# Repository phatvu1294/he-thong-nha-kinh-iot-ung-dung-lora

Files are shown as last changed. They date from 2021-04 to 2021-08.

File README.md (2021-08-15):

# Hệ thống nhà kính IO ứng dụng LoRa
*Hệ thống nhà kính IOT ứng dựng LoRa được phát triển dựa trên ESP32, Arduino, LoRa, MQTT, Nodejs và C# Winform*

### Giới thiệu
Đây là một dự án hoàn toàn mới tại Việt Nam, việc áp dụng IOT và công nghệ LoRa đã mở ra một bước đi mới trong nghành nông nghiệp. Đi đôi với cuộc cách mạng công nghệ 4.0, IOT là một phần thiết yếu để phát triển nông nghiệp. Với việc gần như được áp dụng vào thực tế, càng chứng tỏ đây chính là một dự án cấp thiết, việc nghiên cứu và phát triển thêm sẽ càng giúp cho đất nước chúng ta hội nhập và phát triển hơn nữa.

### Mô hình

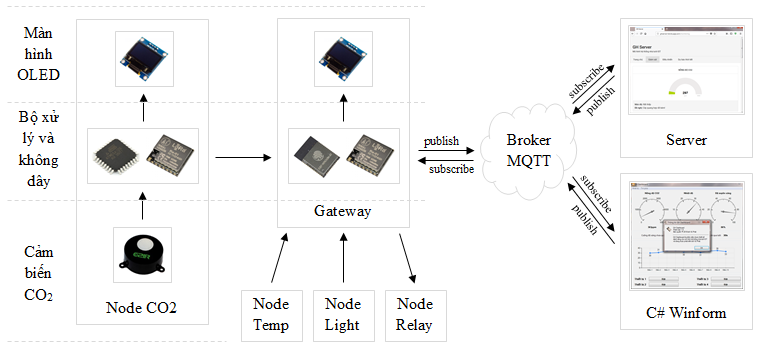
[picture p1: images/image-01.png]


Mô hình lấy Gateway làm trung tâm để xây dựng, Gateway được xây dựng bằng module ESP32, module LoRa Ra-01 và OLED, có nhiệm vụ là chờ tiếp nhận dữ liệu LoRa từ các Node cảm biến (Node CO2, Node Temp, Node Light), xử lý hiển thị OLED và publish chúng lên broker, sau đó được đẩy lên Server hoặc phần mềm điều khiển (C# Winform).

Node cảm biển, cụ thể ở đây là Node CO2 được xây dựng bằng vi điều khiển ATMega328, module LoRa Ra-01, OLED và cảm biến COZIR-AX-5000. Nhiệm vụ là đọc giá trị CO2 và truyền dữ liệu LoRa tới Gateway.

Gateway kết nối với Server hoặc phần mềm thông qua phương thức MQTT, đây là phương thức truyền nhanh, với tốc độ băng thông thấp, … Chúng có dạng publish/subscribe. Khi nhận được dữ liệu LoRa từ Node cảm biến. Gateway xử lý dữ liệu và publish lên broker một message thông qua một topic, lúc này Server hoặc phần mềm sẽ subscribe topic đó và lắng nghe liên tục message từ topic đó, chỉ cần có một dữ liệu gửi lên từ Gateway, lập tức Server và phần mềm sẽ cập nhật giá trị mới theo message đã nhận được, ngược lại, khi Server hoặc Gateway publish dữ liệu, Gateway sẽ subscribe và lắng nghe chúng, nếu có message gửi về từ Server hoặc phần mềm, lập tức Gateway nhận được và chuyển thành dữ liệu LoRa và truyền đi tức thời tới Node điều khiển (Node Relay).

Server được xây dựng trên nền tảng Node.js và phần mềm được xây dựng trên nền tảng C# .NET. Tất cả chúng đều đã có thư viện MQTT hỗ trợ, việc còn lại là do người lập trình sáng tạo chúng như thế nào mà thôi.

### Gateway

Gateway được xây dựng với hạt nhân là module ESP32 và module LoRa Ra-01. Module ESP32 sử dụng chip 32 bit lõi kép cho phép xử lý dữ liệu tốc độ cao, ổn định. Module LoRa Ra-01 sử dụng chip SX1278 hỗ trợ truyền không dây RF lên tận hàng Km.

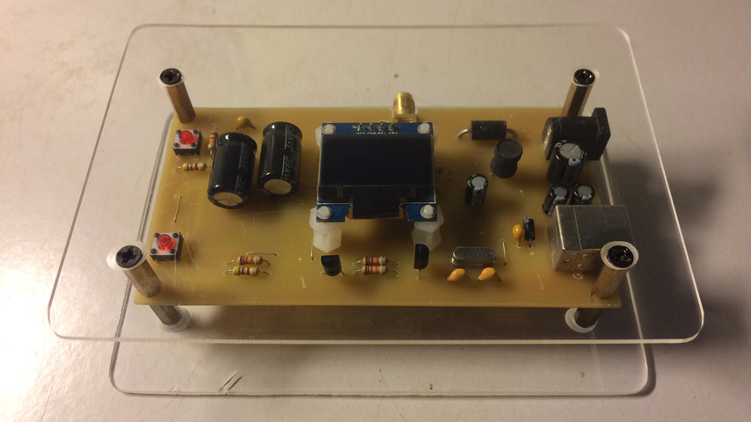
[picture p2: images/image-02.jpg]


### Node CO2

Node CO2 được xây dựng với vđk ATMega328 (Arduino), module LoRa Ra-01 và cảm biến COZIR-AX-5000. Cảm biến COZIR là cảm biến số cho phép đọc giá trị CO2 trực tiếp thông qua UART mà không cần phải tính toán gì nhiều.

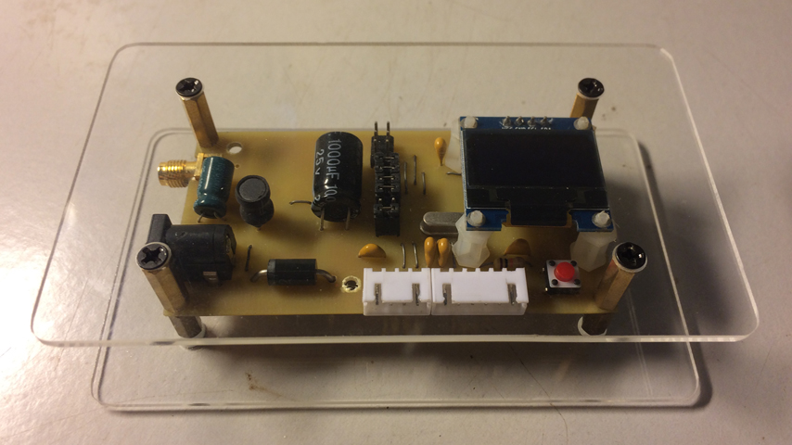
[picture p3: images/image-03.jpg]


### Server Nodejs

Server được xây dựng dựa trên nền tảng Node.js. Với việc sử dụng Socket.io cho phép Server hoạt động thời gian thực. Hệ thống đưa ra khuyến nghị ứng với từng giá trị. Ngoài ra còn có trang dự báo thời tiết cho phép xem tình hình thời tiết trong những ngày sắp tới.

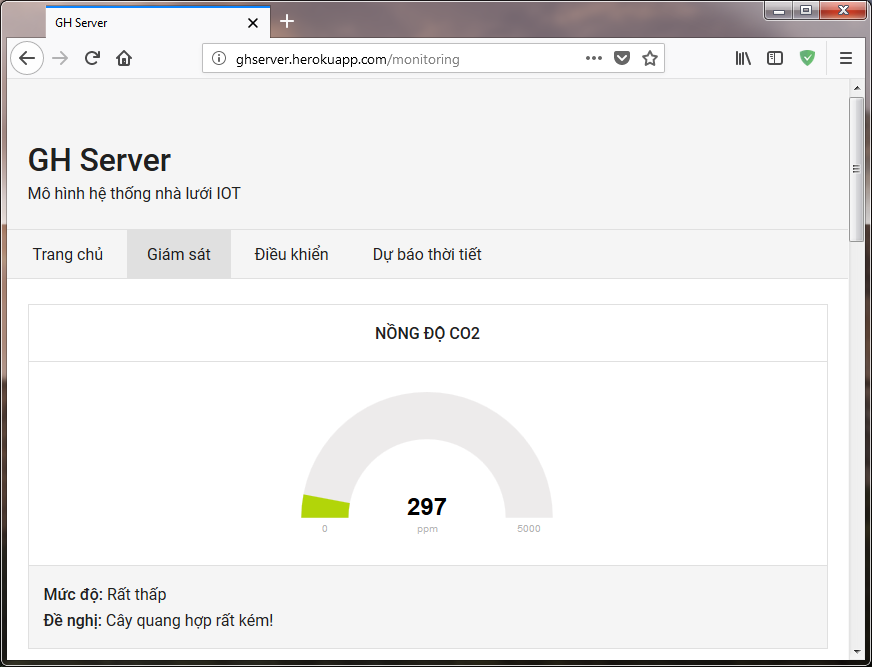
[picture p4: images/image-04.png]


### Phần mềm Winform

Phần mềm được xây dựng dựa trên nền tảng C# .NET. Hỗ trợ nhật ký cho phép người sử dụng theo dõi được sự thay đổi tức thời của các giá trị.

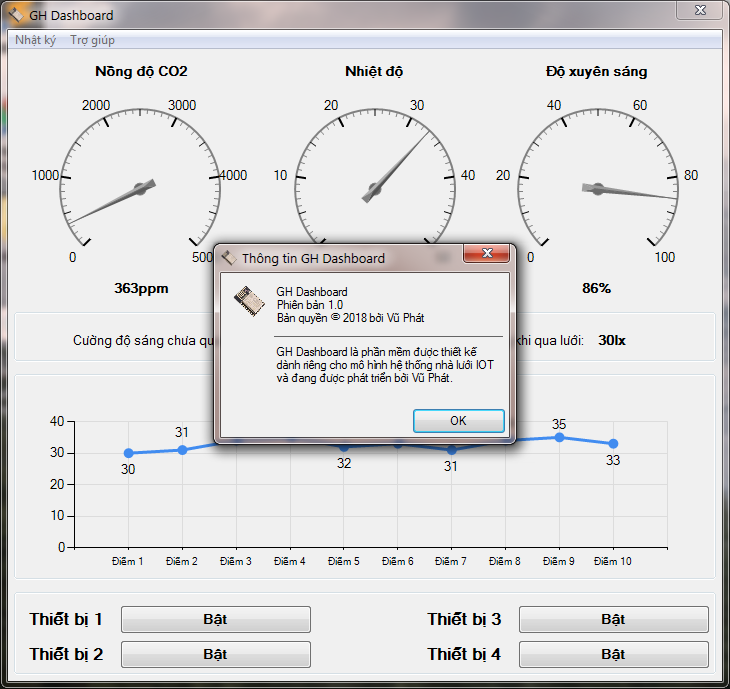
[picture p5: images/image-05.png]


### Video demo hệ thống

[https://www.youtube.com/watch?v=TktAAO-llQs](https://www.youtube.com/watch?v=TktAAO-llQs)

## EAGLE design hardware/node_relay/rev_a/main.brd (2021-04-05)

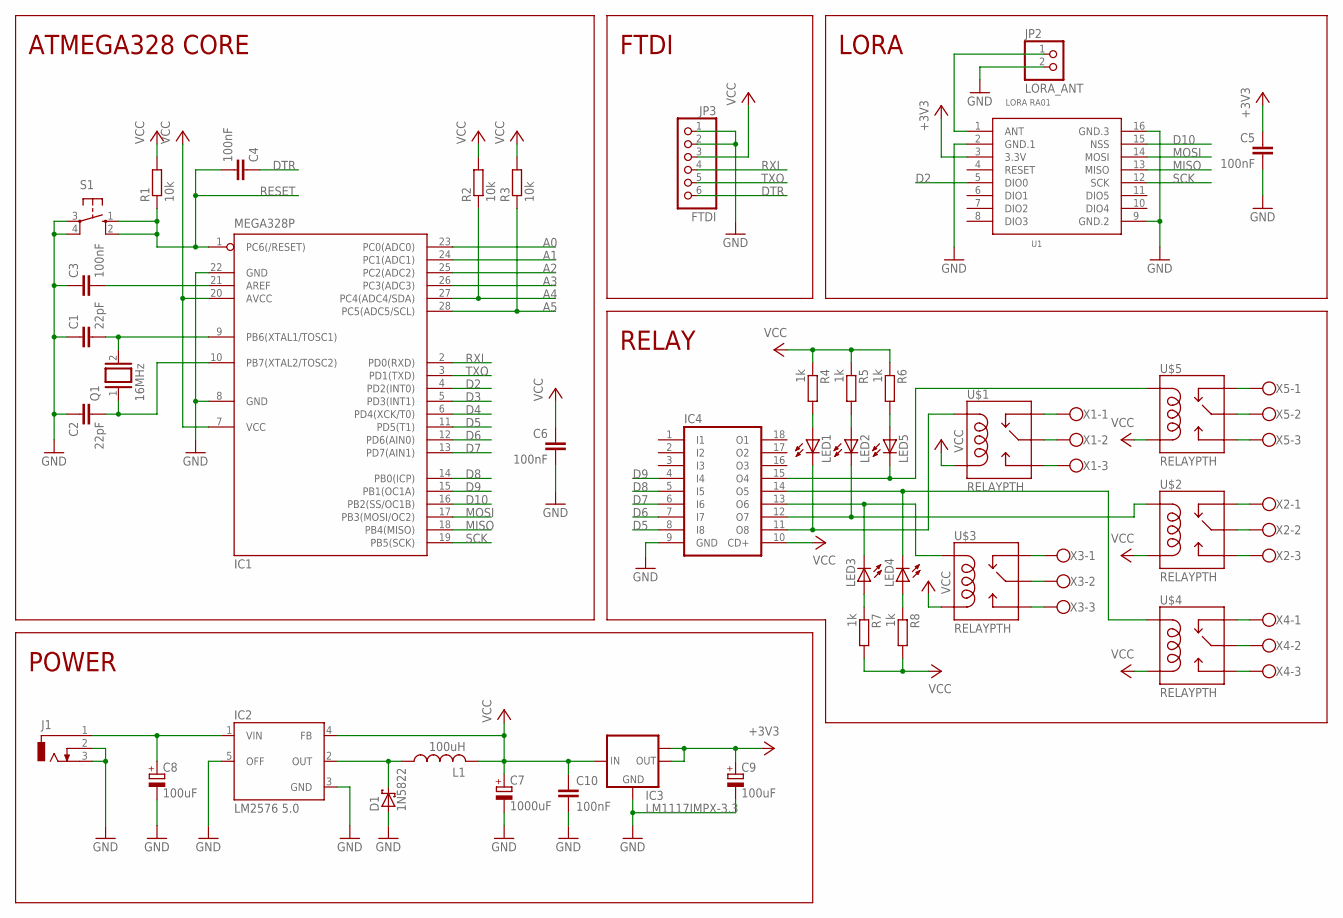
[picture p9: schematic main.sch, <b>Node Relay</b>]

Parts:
C1, C2: 22pF; C050-024X044
C3, C4, C5, C6, C10: 100nF; C050-024X044
C7: 1000uF; E5-13
C8: 100uF; E5-8,5
C9: 100uF; E3,5-10
D1: 1N5822; DO201T15
IC1: MEGA328P; DIL28-3
IC2: LM2576 5.0; TO263-5
IC3: LM1117IMPX-3.3; SOT223
IC4: ULN2803A; DIL18
J1: DCJ0303
JP2: LORA_ANT; 1X02
JP3: FTDI; 1X06
L1: 100uH; 6000-XXXX-RC
LED1, LED2, LED3, LED4, LED5: LED3MM
Q1: 16MHz; QS
R1, R2, R3: 10k; 0207/10
R4, R5, R6, R7, R8: 1k; 0207/10
S1: 10-XX; B3F-10XX
U1: LORA RA01; LORA-RA1-SMD
U$1, U$2, U$3, U$4, U$5: RELAYPTH; SRD-05VDC-SL-C
X1, X2, X3, X4, X5: W237-103

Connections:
+3V3: C5.1, C9.+, IC3.2 (OUT), IC3.TAB (OUT1), U1.3 (3.3V)
A0: IC1.23 (PC0(ADC0))
A1: IC1.24 (PC1(ADC1))
A2: IC1.25 (PC2(ADC2))
A3: IC1.26 (PC3(ADC3))
A4: IC1.27 (PC4(ADC4/SDA)), R2.1
A5: IC1.28 (PC5(ADC5/SCL)), R3.1
D2: IC1.4 (PD2(INT0)), U1.5 (DIO0)
D3: IC1.5 (PD3(INT1))
D4: IC1.6 (PD4(XCK/T0))
D5: IC1.11 (PD5(T1)), IC4.8 (I8)
D6: IC1.12 (PD6(AIN0)), IC4.7 (I7)
D7: IC1.13 (PD7(AIN1)), IC4.6 (I6)
D8: IC1.14 (PB0(ICP)), IC4.5 (I5)
D9: IC1.15 (PB1(OC1A)), IC4.4 (I4)
D10: IC1.16 (PB2(SS/OC1B)), U1.15 (NSS)
DTR: C4.1, JP3.6
GND: C1.1, C2.1, C3.1, C5.2, C6.2, C7.-, C8.-, C9.-, C10.2, D1.A, IC1.8 (GND), IC1.22 (GND), IC2.3 (GND), IC2.5 (OFF), IC3.1 (GND), IC4.9 (GND), J1.2, J1.3, JP2.2, JP3.1, JP3.2, S1.3, S1.4 (P1), U1.2 (GND.1), U1.9 (GND.2), U1.16 (GND.3)
MISO: IC1.18 (PB4(MISO)), U1.13 (MISO)
MOSI: IC1.17 (PB3(MOSI/OC2)), U1.14 (MOSI)
unnamed: JP2.1, U1.1 (ANT)
unnamed: C1.2, IC1.9 (PB6(XTAL1/TOSC1)), Q1.2
unnamed: C2.2, IC1.10 (PB7(XTAL2/TOSC2)), Q1.1
unnamed: C3.2, IC1.21 (AREF)
unnamed: C8.+, IC2.1 (VIN), J1.1
unnamed: D1.C, IC2.2 (OUT), L1.1
unnamed: U$1.SWCLOSED (SWCLOSE), X1.1
unnamed: U$1.SWCOMMON, X1.2
unnamed: U$1.SWOPEN, X1.3
unnamed: U$3.SWCOMMON, X3.2
unnamed: U$3.SWCLOSED (SWCLOSE), X3.1
unnamed: U$3.SWOPEN, X3.3
unnamed: U$4.SWCLOSED (SWCLOSE), X4.1
unnamed: U$4.SWCOMMON, X4.2
unnamed: U$4.SWOPEN, X4.3
unnamed: U$2.SWOPEN, X2.3
unnamed: U$2.SWCLOSED (SWCLOSE), X2.1
unnamed: U$2.SWCOMMON, X2.2
unnamed: IC4.11 (O8), LED1.K (C), U$1.COIL1
unnamed: IC4.12 (O7), LED2.K (C), U$2.COIL1
unnamed: IC4.13 (O6), LED3.K (C), U$3.COIL1
unnamed: IC4.14 (O5), LED4.K (C), U$4.COIL1
unnamed: U$5.SWCLOSED (SWCLOSE), X5.1
unnamed: U$5.SWOPEN, X5.3
unnamed: U$5.SWCOMMON, X5.2
unnamed: IC4.15 (O4), LED5.K (C), U$5.COIL1
unnamed: LED1.A, R4.2
unnamed: LED2.A, R5.2
unnamed: LED5.A, R6.2
unnamed: LED3.A, R7.1
unnamed: LED4.A, R8.1
RESET: C4.2, IC1.1 (PC6(/RESET)), R1.1, S1.1 (S), S1.2 (S1)
RXI: IC1.2 (PD0(RXD)), JP3.4
SCK: IC1.19 (PB5(SCK)), U1.12 (SCK)
TXO: IC1.3 (PD1(TXD)), JP3.5
VCC: C6.1, C7.+, C10.1, IC1.7 (VCC), IC1.20 (AVCC), IC2.4 (FB), IC3.3 (IN), IC4.10 (CD+), JP3.3, L1.2, R1.2, R2.2, R3.2, R4.1, R5.1, R6.1, R7.2, R8.2, U$1.COIL0, U$2.COIL0, U$3.COIL0, U$4.COIL0, U$5.COIL0

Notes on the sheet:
LORA
ATMEGA328 CORE
FTDI
POWER
RELAY

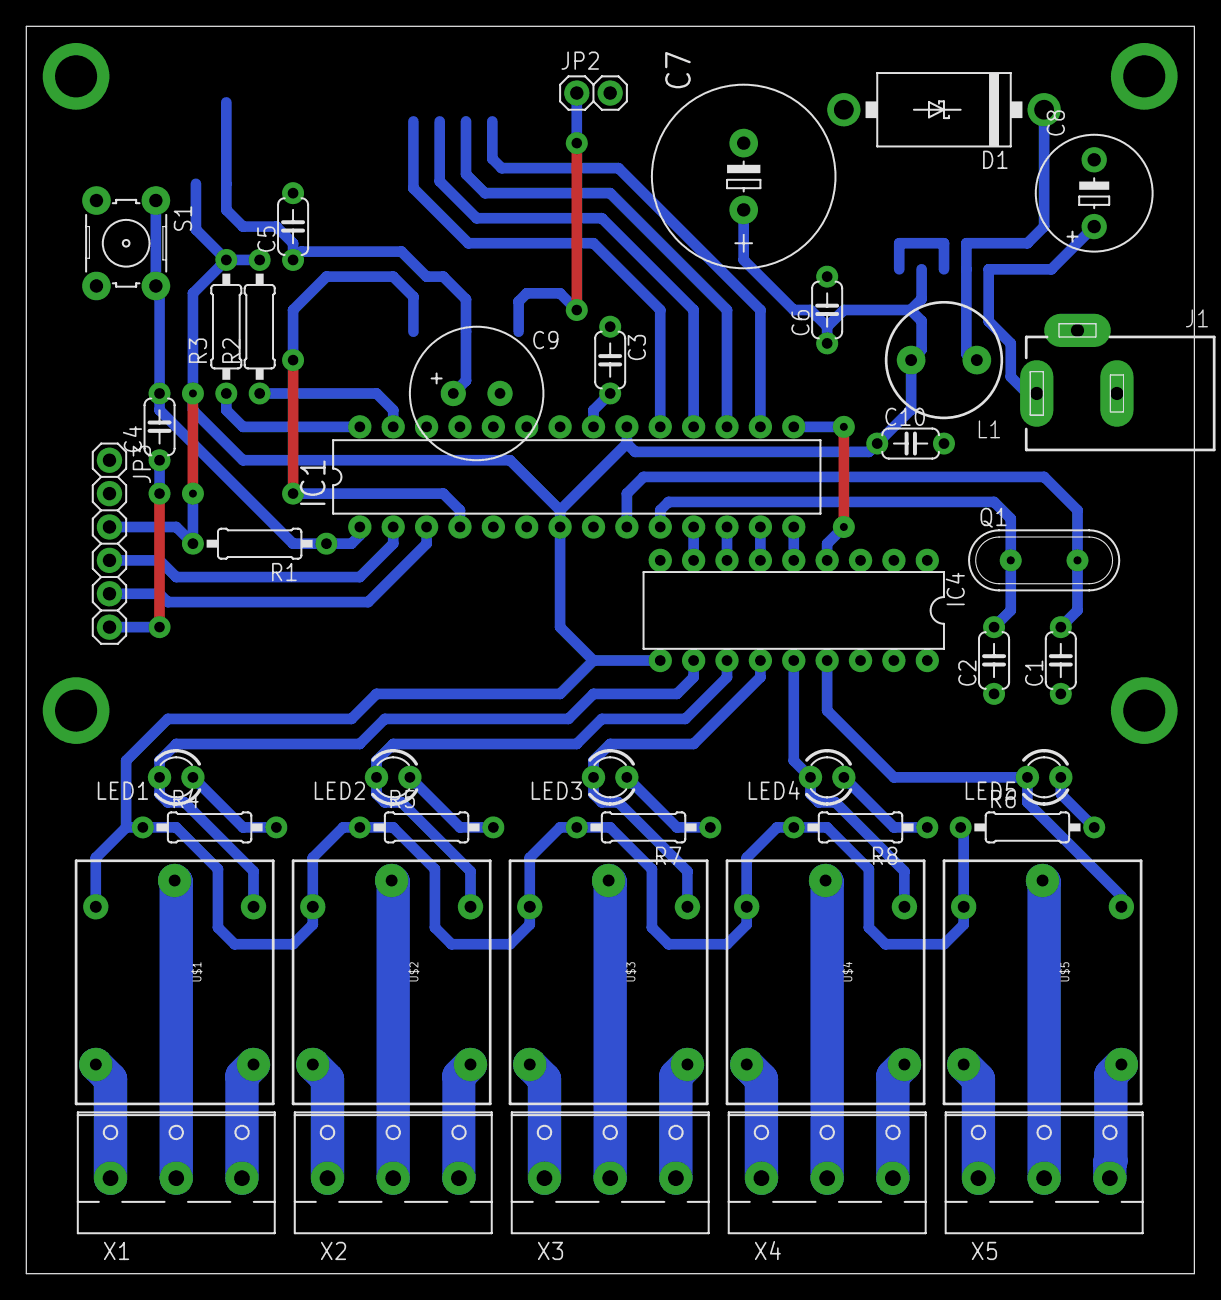
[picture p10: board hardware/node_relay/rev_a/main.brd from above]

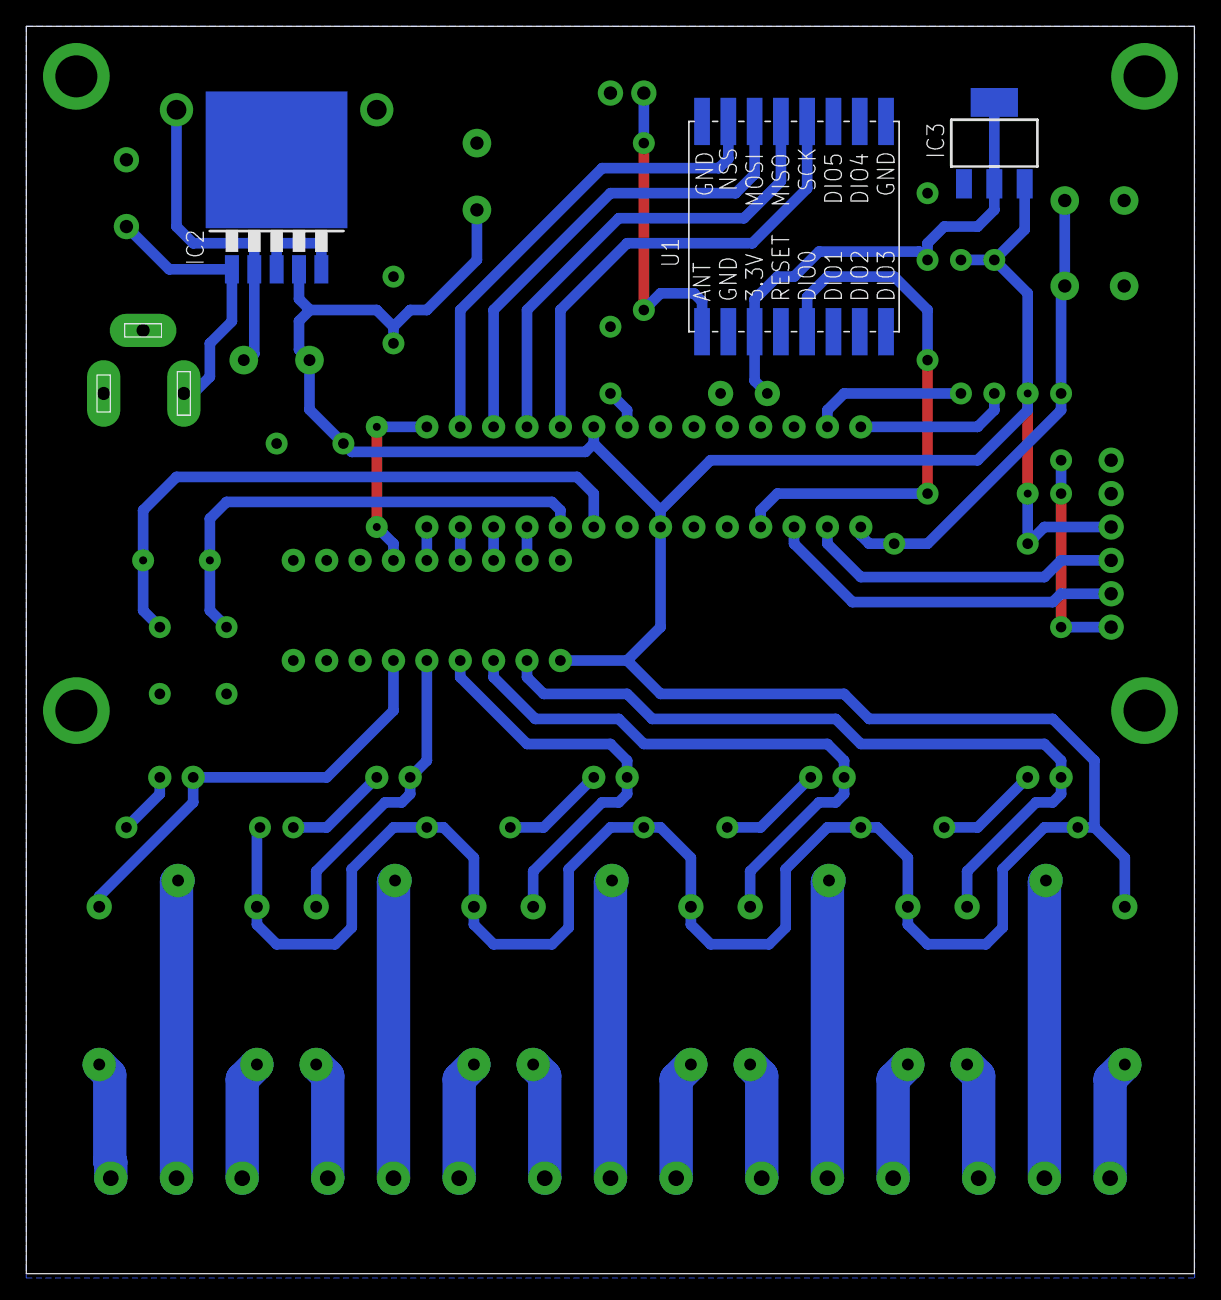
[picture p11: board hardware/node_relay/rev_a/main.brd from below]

Board: 2 copper layers, 88.9 x 94.9 mm, 45 parts (3 on the bottom side), 50 nets.

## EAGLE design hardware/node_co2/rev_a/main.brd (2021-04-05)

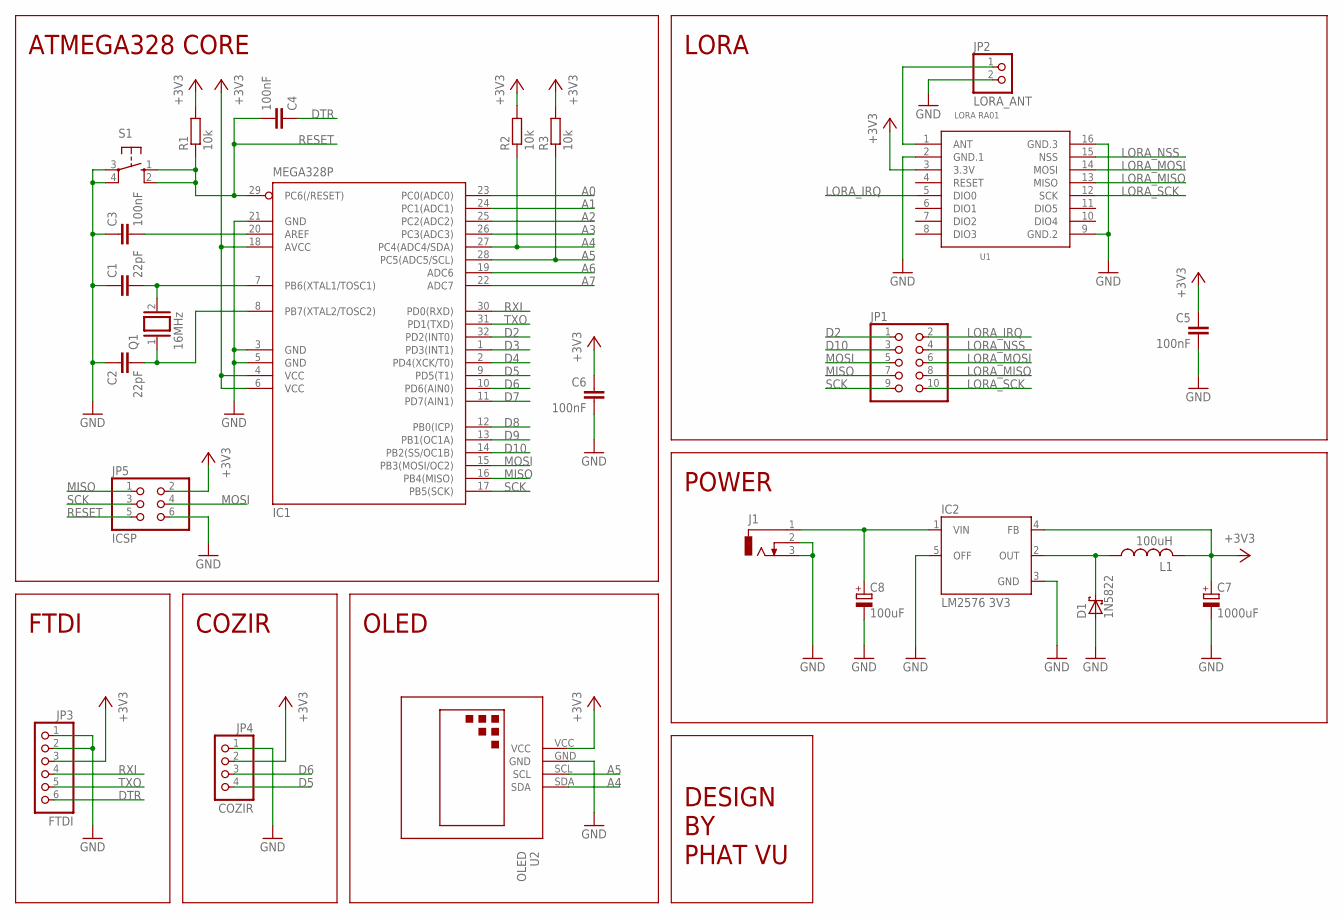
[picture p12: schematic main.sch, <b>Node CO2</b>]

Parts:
C1, C2: 22pF; C050-024X044
C3, C4, C5, C6: 100nF; C050-024X044
C7: 1000uF; E5-13
C8: 100uF; E5-8,5
D1: 1N5822; DO201T15
IC1: MEGA328P; TQFP32-08
IC2: LM2576 3V3; TO263-5
J1: DCJ0303
JP1: PINHD-2X5; 2X05
JP2: LORA_ANT; 1X02
JP3: FTDI; 1X06
JP4: COZIR; 1X04
JP5: ICSP; 2X03
L1: 100uH; 6000-XXXX-RC
Q1: 16MHz; QS
R1, R2, R3: 10k; 0207/10
S1: 10-XX; B3F-10XX
U1: LORA RA01; LORA-RA1-SMD
U2: OLED; OLED-096-I2C

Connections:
+3V3: C5.1, C6.1, C7.+, IC1.4 (VCC), IC1.6 (VCC), IC1.18 (AVCC), IC2.4 (FB), JP3.3, JP4.2, JP5.2, L1.2, R1.2, R2.2, R3.2, U1.3 (3.3V), U2.VCC
A0: IC1.23 (PC0(ADC0))
A1: IC1.24 (PC1(ADC1))
A2: IC1.25 (PC2(ADC2))
A3: IC1.26 (PC3(ADC3))
A4: IC1.27 (PC4(ADC4/SDA)), R2.1, U2.SDA
A5: IC1.28 (PC5(ADC5/SCL)), R3.1, U2.SCL
A6: IC1.19 (ADC6)
A7: IC1.22 (ADC7)
D2: IC1.32 (PD2(INT0)), JP1.1
D3: IC1.1 (PD3(INT1))
D4: IC1.2 (PD4(XCK/T0))
D5: IC1.9 (PD5(T1)), JP4.4
D6: IC1.10 (PD6(AIN0)), JP4.3
D7: IC1.11 (PD7(AIN1))
D8: IC1.12 (PB0(ICP))
D9: IC1.13 (PB1(OC1A))
D10: IC1.14 (PB2(SS/OC1B)), JP1.3
DTR: C4.1, JP3.6
GND: C1.1, C2.1, C3.1, C5.2, C6.2, C7.-, C8.-, D1.A, IC1.3 (GND), IC1.5 (GND), IC1.21 (GND), IC2.3 (GND), IC2.5 (OFF), J1.2, J1.3, JP2.2, JP3.1, JP3.2, JP4.1, JP5.6, S1.3, S1.4 (P1), U1.2 (GND.1), U1.9 (GND.2), U1.16 (GND.3), U2.GND
LORA_IRQ: JP1.2, U1.5 (DIO0)
LORA_MISO: JP1.8, U1.13 (MISO)
LORA_MOSI: JP1.6, U1.14 (MOSI)
LORA_NSS: JP1.4, U1.15 (NSS)
LORA_SCK: JP1.10, U1.12 (SCK)
MISO: IC1.16 (PB4(MISO)), JP1.7, JP5.1
MOSI: IC1.15 (PB3(MOSI/OC2)), JP1.5, JP5.4
unnamed: JP2.1, U1.1 (ANT)
unnamed: C1.2, IC1.7 (PB6(XTAL1/TOSC1)), Q1.2
unnamed: C2.2, IC1.8 (PB7(XTAL2/TOSC2)), Q1.1
unnamed: C3.2, IC1.20 (AREF)
unnamed: C8.+, IC2.1 (VIN), J1.1
unnamed: D1.C, IC2.2 (OUT), L1.1
RESET: C4.2, IC1.29 (PC6(/RESET)), JP5.5, R1.1, S1.1 (S), S1.2 (S1)
RXI: IC1.30 (PD0(RXD)), JP3.4
SCK: IC1.17 (PB5(SCK)), JP1.9, JP5.3
TXO: IC1.31 (PD1(TXD)), JP3.5

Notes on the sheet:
LORA
ATMEGA328 CORE
FTDI
COZIR
OLED
POWER
DESIGN BY PHAT VU

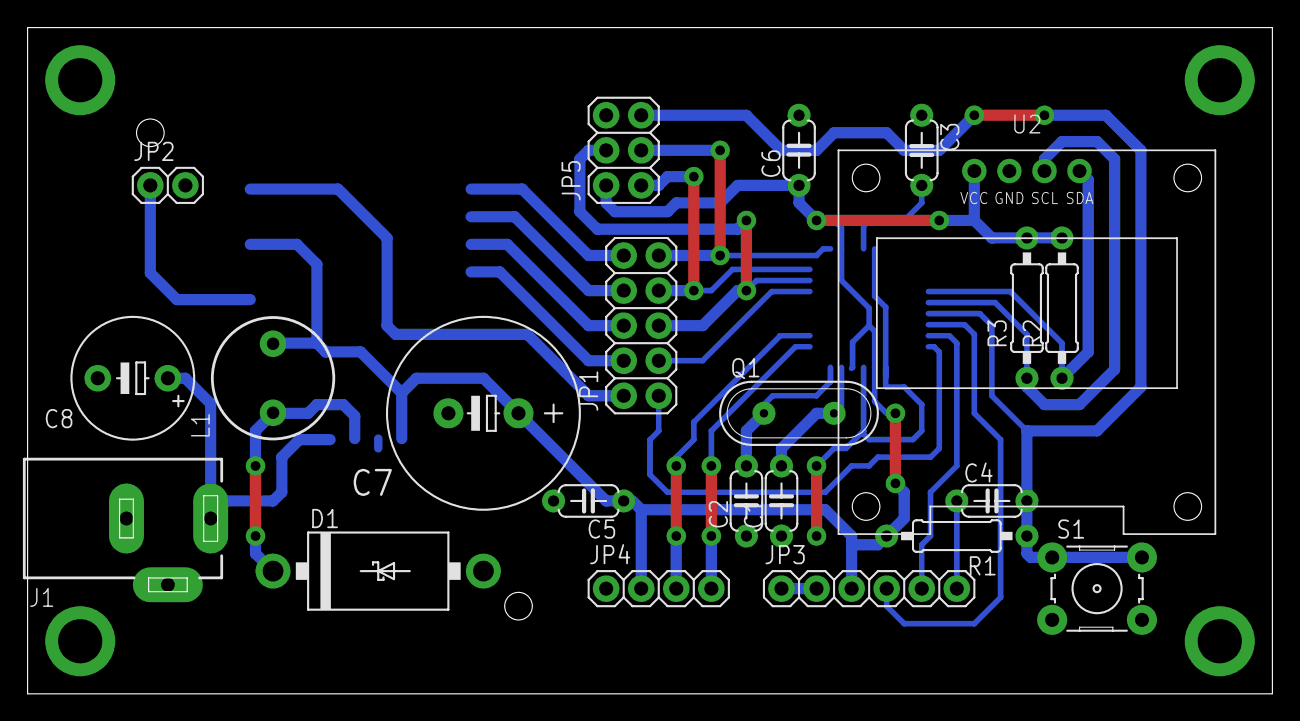
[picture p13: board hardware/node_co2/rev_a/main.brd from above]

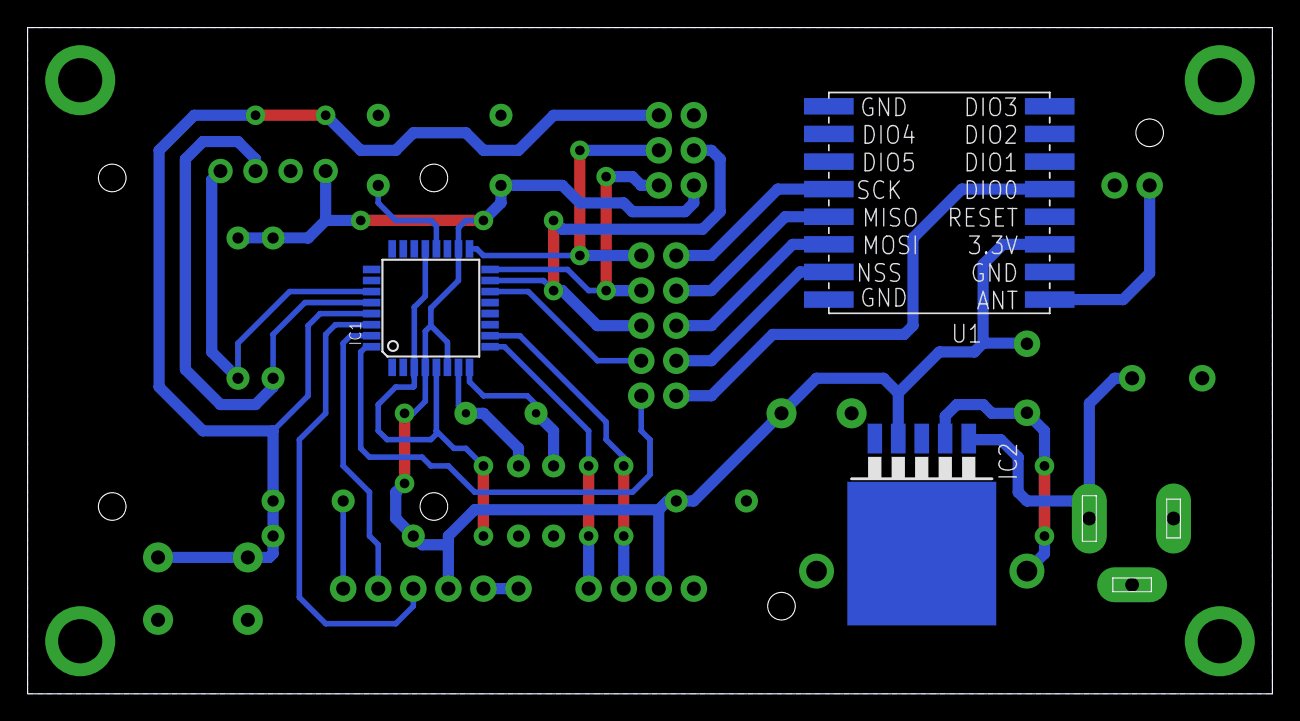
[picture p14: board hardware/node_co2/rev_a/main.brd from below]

Board: 2 copper layers, 90.2 x 48.3 mm, 25 parts (3 on the bottom side), 26 nets.

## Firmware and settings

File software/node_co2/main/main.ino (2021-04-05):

/*******************************************************************************
  Bao gồm
*******************************************************************************/

// Thư viện OLED
#include "ssd1306.h"
#include "images.h"

// Thư viện COZIR
#include <SoftwareSerial.h>
#include "cozir.h"

// Thư viện Lora
#include <SPI.h>
#include <RHDatagram.h>
#include <RH_RF95.h>

/*******************************************************************************
  Định nghĩa
*******************************************************************************/

// Địa chỉ Lora
#define GATEWAY_ADDRESS     0
#define NODECO2_ADDRESS     1

/*******************************************************************************
  Biến
*******************************************************************************/

// Lora
RH_RF95 driver;
RHDatagram manager(driver, NODECO2_ADDRESS);
bool loraSendOK = false, loraReceiveOK = false;
unsigned long loraSendMillis = 0, loraReceiveMillis = 0, loraInterval = 2000;

// COZIR
SoftwareSerial nss(5, 6);
COZIR czr(nss);

// Mảng giá trị CO2
char co2Arr[6];

// Định thời
unsigned long previousMillis = 0;
unsigned long interval = 1000;

/*******************************************************************************
  Hàm khởi tạo
*******************************************************************************/

void setup() {
  // Khỏi tạo OLED
  ssd1306_128x64_i2c_init();

  // Đầy màn hình
  ssd1306_fillScreen(0x00);

  // Đặt phông chữ
  ssd1306_setFixedFont(ssd1306xled_font6x8);

  // Hiển thị bản quyền tác giả và hình sản phẩm
  ssd1306_printFixed(14,  0, "(c) 2018 PHAT VU", STYLE_NORMAL);
  ssd1306_drawBitmap(0, 18, Product_bg_width, Product_bg_height, Product_bg_bits);

  // COZIR chế độ 2
  czr.SetOperatingMode(CZR_POLLING);

  // COZIR hiệu chỉnh không khí
  czr.CalibrateFreshAir();

  delay(3000);

  // Xóa màn hình
  ssd1306_clearScreen();

  // Hiển thị tên sản phẩm
  ssd1306_printFixed(66, 0, "NODE", STYLE_NORMAL);
  ssd1306_printFixed(66, 8, "v1.0", STYLE_NORMAL);
  ssd1306_printFixedN(92, 0, "CO2", STYLE_NORMAL, FONT_SIZE_2X);

  // Khởi tạo Lora
  manager.init();

  // Lora chế độ PA Boost 20dBm (Chậm + Khoảng cách xa)
  //driver.setModemConfig(RH_RF95::Bw31_25Cr48Sf512);
  //driver.setTxPower(20);
}

/*******************************************************************************
  Hàm lặp vô hạn
*******************************************************************************/

void loop() {
  // Hiển thị biểu tượng lora
  ssd1306_drawBitmap(0, 0, Lora_icon_width, Lora_icon_height, Lora_icon_bits);

  // Nếu Lora gửi thành công thì hiện biểu tượng gửi thành công và ngược lại
  if (loraSendOK) {
    ssd1306_drawBitmap(16, 0, Send_icon_width, Send_icon_height, Send_icon_bits);
  } else {
    ssd1306_drawBitmap(16, 0, Default_icon_width, Default_icon_height, Default_icon_bits);
  }

  // Nếu Lora nhận thành công thì hiện biểu tượng nhận thành công và ngược lại
  if (loraReceiveOK) {
    ssd1306_drawBitmap(16, 9, Receive_icon_width, Receive_icon_height, Receive_icon_bits);
  } else {
    ssd1306_drawBitmap(16, 9, Default_icon_width, Default_icon_height, Default_icon_bits);
  }

  // Nếu Lora sẵn sàng
  if (manager.available()) {
    // Biến bộ đệm
    uint8_t buf[RH_RF95_MAX_MESSAGE_LEN];

    // Biến độ rộng bộ đệm
    uint8_t len = sizeof(buf);

    // Biến địa chỉ Lora
    uint8_t from;

    // Nếu nhận được dữ liệu Lora
    if (manager.recvfrom(buf, &len, &from)) {

      // Nếu từ Gateway
      if (from == GATEWAY_ADDRESS) {
        // Lora nhận thành công
        loraReceiveOK = true;
        loraReceiveMillis = millis();

        delay(500);

        // Nếu gửi giá trị CO2 đến Gateway thành công
        if (manager.sendto((uint8_t *)co2Arr, (uint8_t)sizeof(co2Arr), GATEWAY_ADDRESS)) {
          // Lora gửi thành công
          loraSendOK = true;
          loraSendMillis = millis();
        }
      }
    }
  }

  // Biến thời điểm hiện tại
  unsigned long currentMillis1 = millis();

  // Chạy định thời với sau khoảng thời gian đặt trước
  if (currentMillis1 - previousMillis >= interval || previousMillis == 0) {
    previousMillis = currentMillis1;

    // Biến giá trị CO2
    int co2 = (int)czr.CO2();

    // Chuỗi giá trị CO2
    String co2Str = String(co2);

    // Chuyển chuỗi giá trị CO2 sang mảng giá trị CO2
    co2Str.toCharArray(co2Arr, sizeof(co2Arr));

    // Hiển thị hình CO2
    ssd1306_drawBitmap(0, 18, CO2_bg_width, CO2_bg_height, CO2_bg_bits);

    // Hiển thị tiêu đề CO2
    ssd1306_printFixed(50, 27, "Nong do (ppm)", STYLE_NORMAL);

    // Xóa giá trị CO2 hiện hành
    ssd1306_clearBlock(50, 45, 78, 16);

    // Hiển thị giá trị CO2
    ssd1306_printFixedN(64, 45, co2Str.c_str(), STYLE_NORMAL, FONT_SIZE_2X);
  }

  // Biến thời điểm hiện tại
  unsigned long currentMillis2 = millis();

  // Ẩn biểu tượng Lora gửi thành công sau thời gian định trước
  if ((currentMillis2 - loraSendMillis >= loraInterval) && loraSendOK) {
    loraSendOK = false;
  }

  // Ẩn biểu tượng Lora nhận thành công sau thời gian định trước
  if ((currentMillis2 - loraReceiveMillis >= loraInterval) && loraReceiveOK) {
    loraReceiveOK = false;
  }
}

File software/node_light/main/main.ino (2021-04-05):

/*******************************************************************************
  Bao gồm
*******************************************************************************/

// Thư viện LCD
#include <LiquidCrystal.h>

// Thư viện BH1750
#include <Wire.h>
#include <BH1750.h>

// Thư viện Lora
#include <RHDatagram.h>
#include <RH_RF95.h>
#include <SPI.h>

/*******************************************************************************
  Định nghĩa
*******************************************************************************/

// Địa chỉ Lora
#define GATEWAY_ADDRESS     0
#define NODELIGHT_ADDRESS   3

// Ký tự tự tạo
byte sendChar[] = {0x01, 0x03, 0x05, 0x01, 0x01, 0x01, 0x01, 0x00};
byte receiveChar[] = {0x10, 0x10, 0x10, 0x10, 0x14, 0x18, 0x10, 0x00};

/*******************************************************************************
  Biến
*******************************************************************************/

// LCD
LiquidCrystal lcd(9, 8, 7, 6, 5, 4);

// BH1750
BH1750 lightMeter1(0x23);
BH1750 lightMeter2(0x5c);

// Lora
RH_RF95 driver;
RHDatagram manager(driver, NODELIGHT_ADDRESS);
bool loraSendOK = false, loraReceiveOK = false;
unsigned long loraSendMillis = 0, loraReceiveMillis = 0, loraInterval = 2000;

// Mảng cường độ sáng
char lightArr[13];

// Định thời
unsigned long previousMillis = 0;
unsigned long interval = 1000;

/*******************************************************************************
  Hàm khởi tạo
*******************************************************************************/

void setup() {
  // Khởi tạo LCD
  lcd.begin(16, 2);
  lcd.createChar(0, sendChar);
  lcd.createChar(1, receiveChar);

  // Hiển thị bản quyền và tác giả
  lcd.setCursor(0, 0);
  lcd.print("NODE LIGHT  v1.0");
  lcd.setCursor(0, 1);
  lcd.print("(c) 2018 PHAT VU");

  // Khởi tạo BH1750
  Wire.begin();
  lightMeter1.begin();
  lightMeter2.begin();

  // Khởi tạo Lora
  manager.init();

  // Lora chế độ PA Boost 20dBm (Chậm + Khoảng cách xa)
  //driver.setModemConfig(RH_RF95::Bw31_25Cr48Sf512);
  //driver.setTxPower(20);

  delay(3000);

  // Xoá màn hình
  lcd.clear();
}

/*******************************************************************************
  Hàm lặp vô hạn
*******************************************************************************/

void loop() {
  // Nếu Lora gửi thành công thì hiện biểu tượng gửi thành công và ngược lại
  if (loraSendOK) {
    lcd.setCursor(14, 0);
    lcd.write((uint8_t)0);
  } else {
    lcd.setCursor(14, 0);
    lcd.print(" ");
  }

  // Nếu Lora nhận thành công thì hiện biểu tượng nhận thành công và ngược lại
  if (loraReceiveOK) {
    lcd.setCursor(15, 0);
    lcd.write((uint8_t)1);
  } else {
    lcd.setCursor(15, 0);
    lcd.print(" ");
  }

  // Biến thời điểm hiện tại
  unsigned long currentMillis1 = millis();

  // Chạy định thời với thời gian đặt trước
  if (currentMillis1 - previousMillis >= interval || previousMillis == 0) {
    previousMillis = currentMillis1;

    // Biến hiển thị dữ liệu
    char data[17];

    // Đọc cường độ sáng từ các cảm biến
    uint8_t lux1 = lightMeter1.readLightLevel();
    uint8_t lux2 = lightMeter2.readLightLevel();

    // Hiển thị cường độ sáng trước và sau khi qua lưới
    sprintf(data, "TR: %d lx     ", lux1);
    lcd.setCursor(0, 0);
    lcd.print(data);
    sprintf(data, "SA: %d lx     ", lux2);
    lcd.setCursor(0, 1);
    lcd.print(data);

    // Tính độ xuyên sáng
    int level = 0;
    if (lux1 != 0) level = round(lux2 * 100.0 / lux1);

    // Hiển thị độ xuyên sáng
    sprintf(data, "%4d%%   ", level);
    lcd.setCursor(11, 1);
    lcd.print(data);

    // In ra mảng cường độ sáng có định dạng trước
    sprintf(lightArr, "%d,%d", lux1, lux2);
  }

  // Nếu Lora sẵn sàng
  if (manager.available()) {
    // Biến bộ đệm
    uint8_t buf[RH_RF95_MAX_MESSAGE_LEN];

    // Biến độ rộng bộ đệm
    uint8_t len = sizeof(buf);

    // Biến địa chỉ Lora
    uint8_t from;

    // Nếu nhận được dữ liệu Lora
    if (manager.recvfrom(buf, &len, &from)) {

      // Nếu từ Gateway
      if (from == GATEWAY_ADDRESS) {
        // Lora nhận thành công
        loraReceiveOK = true;
        loraReceiveMillis = millis();

        delay(500);

        // Nếu gửi giá trị CO2 đến Gateway thành công
        if (manager.sendto((uint8_t *)lightArr, (uint8_t)sizeof(lightArr), GATEWAY_ADDRESS)) {
          // Lora gửi thành công
          loraSendOK = true;
          loraSendMillis = millis();
        }
      }
    }
  }

  // Biến thời điểm hiện tại
  unsigned long currentMillis2 = millis();

  // Ẩn biểu tượng Lora gửi thành công sau thời gian định trước
  if ((currentMillis2 - loraSendMillis >= loraInterval) && loraSendOK) {
    loraSendOK = false;
  }

  // Ẩn biểu tượng Lora nhận thành công sau thời gian định trước
  if ((currentMillis2 - loraReceiveMillis >= loraInterval) && loraReceiveOK) {
    loraReceiveOK = false;
  }
}

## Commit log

2021-04-05 upload source
    [main.brd, main.sch]
2021-04-05 sửa readme.md
